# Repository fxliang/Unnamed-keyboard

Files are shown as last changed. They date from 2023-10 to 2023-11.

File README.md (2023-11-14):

The Unnamed Keyboard is a 42-key, diodeless, flippable, low profile choc v1 or MX 3 pin switch hotswap, IO protected, aggressive column staggered, programmable ergonomic mechnical split keyboard powered by Rasyberry Pi Pico or other compatible RP2040 boards. It is based on the [Piantor](https://github.com/beekeeb/piantor) Keyboard. 
## Features

* Powered by RP2040 MCU with Raspberry Pi Pico
* Cantor & Corne like layout
* Flippable layout
* Diodeless
* Split hand pin for automatically left hand detection, single firmware for both sides
* TRRS with resistor protection, hot-plug no damage 
* Hybrid hotswap: low profile choc switches and MX switches(3pin)

## BOM
* Raspberry Pi Pico (or compatible one) * 2
* choc swtiches / MX(3pin) switches * 42
* hotswap sockets for choc swtiches / MX(3pin) switches * 42
* TRRS sockets * 2, C128990(JLC),or PJ-393-7P in tb.
* 3.5mm TRRS wire (4 pin)
* 100r 0805 resistor * 4 (for io protection)
* 1k 0805 resistor *  2 (for hand pin detection)

## Images
top left
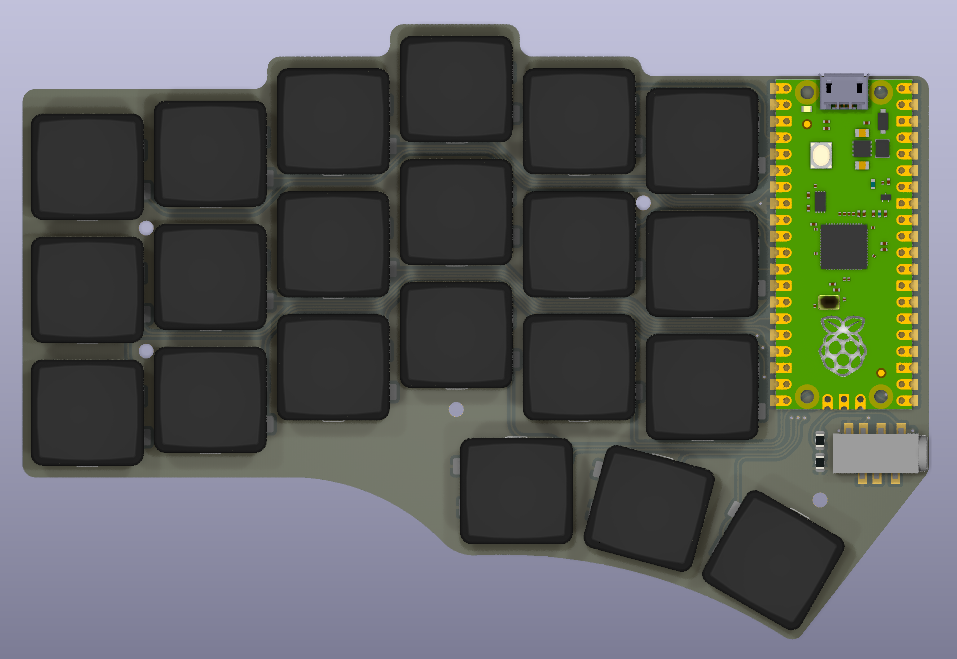
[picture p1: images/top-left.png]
left-top


bottom left(ignore the TRRS connector and pico:)
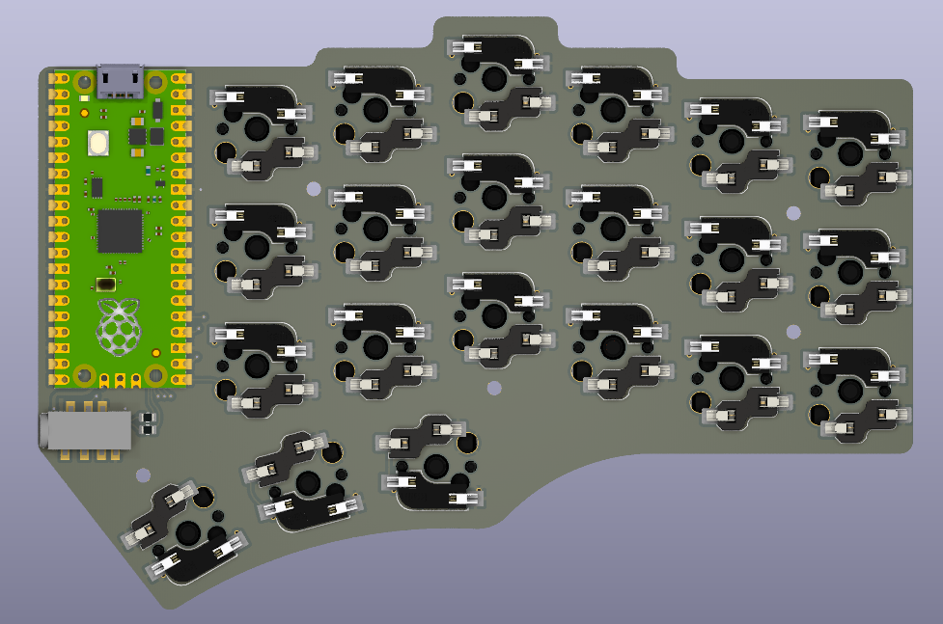
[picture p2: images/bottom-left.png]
bottom-top


pcb top
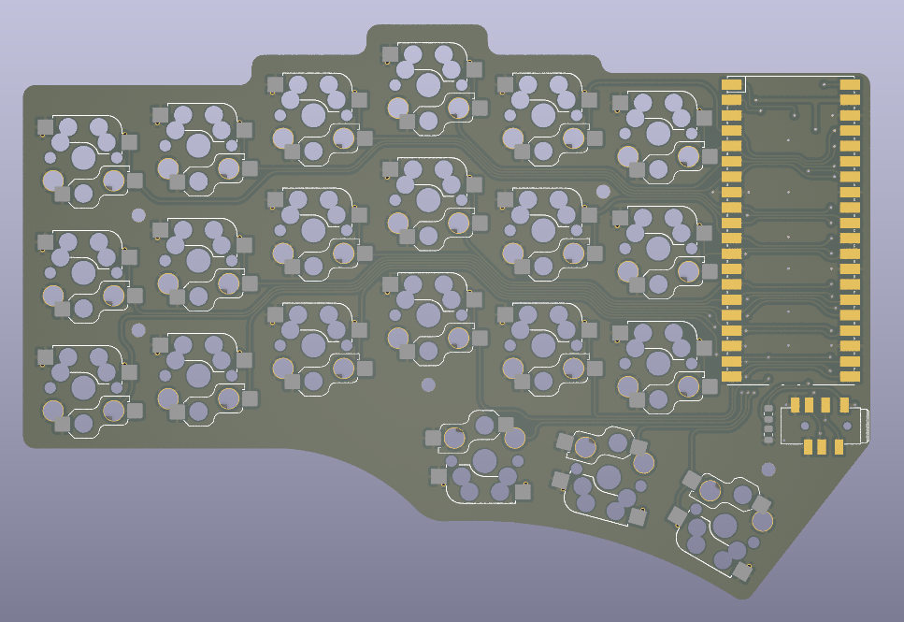
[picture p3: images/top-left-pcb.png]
pcb top


pcb bottom
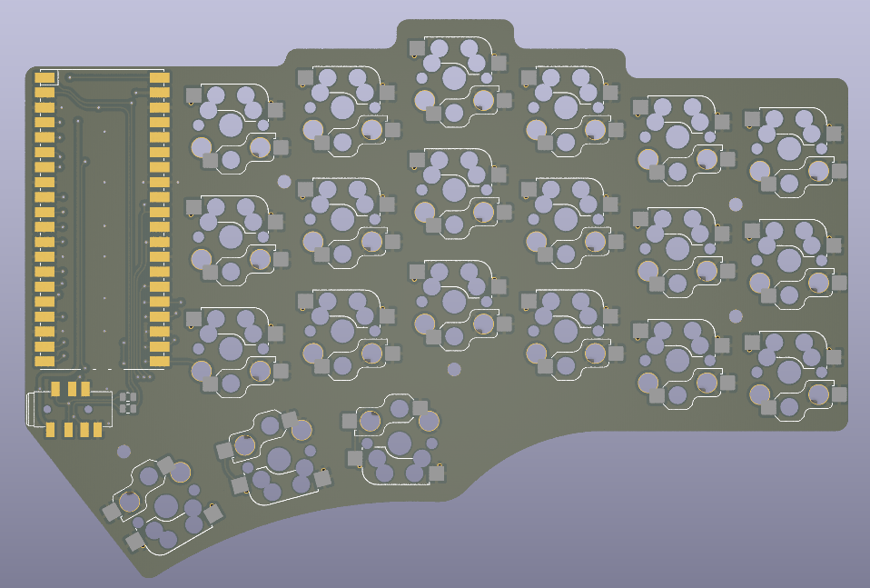
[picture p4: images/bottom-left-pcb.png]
pcb bottom


first made 


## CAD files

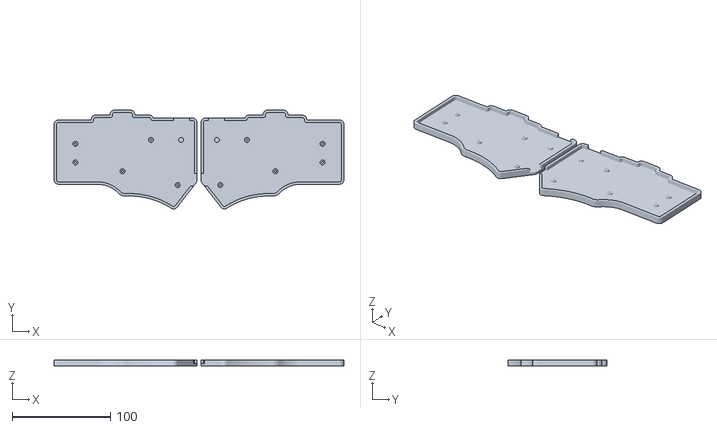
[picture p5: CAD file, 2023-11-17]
case.stl
294.8 x 100.4 x 6.30

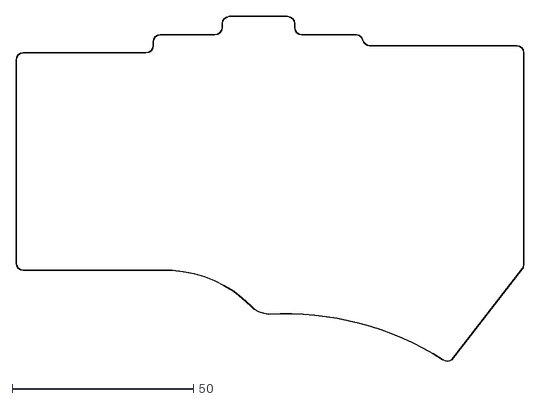
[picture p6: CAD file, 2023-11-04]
dxfs/unnamed-Edge_Cuts.dxf
140.0 x 95.1

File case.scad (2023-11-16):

$fn = 256;
pcb_edge_file = "dxfs/unnamed-Edge_Cuts.dxf";
// board parameters, unit: mm
socket_1350_thickness = 1.8;
solder_thickness = 0.2;
board_thickness = 1.6;
shell_thickness = 2.5;
asm_gap = 0.2;
// case cut info, top left 0, 0
type_c_cut_x = 133.5;
type_c_cut_y = -61.5;
type_c_cut_width = 15.8;
type_c_cut_height = 13;
trrs_cut_x = 119;
trrs_cut_y = 0;
trrs_cut_width = 16;
trrs_cut_height = 10;
// board info
board_width = 140;
board_height = 95.0130;
// gap between two cases
case_gap_l2r = 4;
// ----------------------------------------------------------------------------

total_case_height = shell_thickness + socket_1350_thickness + solder_thickness 
+ board_thickness + asm_gap;
shell_diff_height = total_case_height;
case_width = (asm_gap+shell_thickness)*2 + board_width;
offset_base_pcb = shell_thickness + asm_gap;
// ----------------------------------------------------------------------------
// case outline with offset 
module offset_shape() {
  offset(r=offset_base_pcb) import(pcb_edge_file);
}

// extrude base body, from z = 0
module base(){
  linear_extrude(height=total_case_height, center=false) {
    offset_shape();
  }
}

// add asm gap for assembly
module shape_of_shell_diff() {
    offset(r=asm_gap) import(pcb_edge_file);
}

// extrude shape for diff shell
module shell_diff() {
  translate([0, 0, shell_thickness ])
  linear_extrude(height = shell_diff_height, center = false) {
    shape_of_shell_diff();
  }
}
// type_c connector cut
module type_c_diff() {
  translate([type_c_cut_x, type_c_cut_y - type_c_cut_height, shell_thickness])
  cube([type_c_cut_width, type_c_cut_height, total_case_height]);
}

// trrs connector cut
module trrs_diff() {
  translate([trrs_cut_x, trrs_cut_y, shell_thickness])
  // mirror y axis
  mirror([0, -1, 0])
  cube([trrs_cut_width, trrs_cut_height, total_case_height]);
}

// shell case difference by  base() and shell_diff()
module shell_shape() {
  difference(){
    base();
    // cut type_c_diff
    type_c_diff();
    // cut trrs_diff
    trrs_diff();
    // cut shell
    shell_diff();
  }
}

module mount_poles() {
  translate([19.1, -31.6, shell_thickness]) {
    cylinder(h = socket_1350_thickness + solder_thickness, r = shell_thickness);
  }
  translate([19.1, -50.5, shell_thickness]) {
    cylinder(h = socket_1350_thickness + solder_thickness, r = shell_thickness);
  }
  translate([67.0, -59.5, shell_thickness]) {
    cylinder(h = socket_1350_thickness + solder_thickness, r = shell_thickness);
  }
  translate([95.9, -27.6, shell_thickness]) {
    cylinder(h = socket_1350_thickness + solder_thickness, r = shell_thickness);
  }
  translate([126.5, -27.6, shell_thickness]) {
    cylinder(h = socket_1350_thickness + solder_thickness, r = shell_thickness);
  }
  translate([123, -73.5, shell_thickness]) {
    cylinder(h = socket_1350_thickness + solder_thickness, r = shell_thickness);
  }
}
module mount_holes() {
  translate([19.1, -31.6, -shell_thickness]) {
    cylinder(h = total_case_height*2, r = 1);
  }
  translate([19.1, -50.5, -shell_thickness]) {
    cylinder(h = total_case_height*2, r = 1);
  }
  translate([67.0, -59.5, -shell_thickness]) {
    cylinder(h = total_case_height*2, r = 1);
  }
  translate([95.9, -27.6, -shell_thickness]) {
    cylinder(h = total_case_height*2, r = 1);
  }
  translate([123, -73.5, -shell_thickness]) {
    cylinder(h = total_case_height*2, r = 1);
  }
}
// left case
module left_case() {
  // move the left of case to x = 0
  difference() {
    translate([(shell_thickness + asm_gap), 0, 0]){
        mount_poles();
        shell_shape();
    }
    translate([(shell_thickness + asm_gap), 0, 0]){
        mount_holes();
    }
  }
}

// right case
module right_case() {
  // move to the right, add case_gap_l2r
  translate([case_width*2 + case_gap_l2r, 0, 0])
  // mirror x axis
  mirror([-1,0,0])
  // left case
  left_case();
}
// use modules
left_case();
right_case();

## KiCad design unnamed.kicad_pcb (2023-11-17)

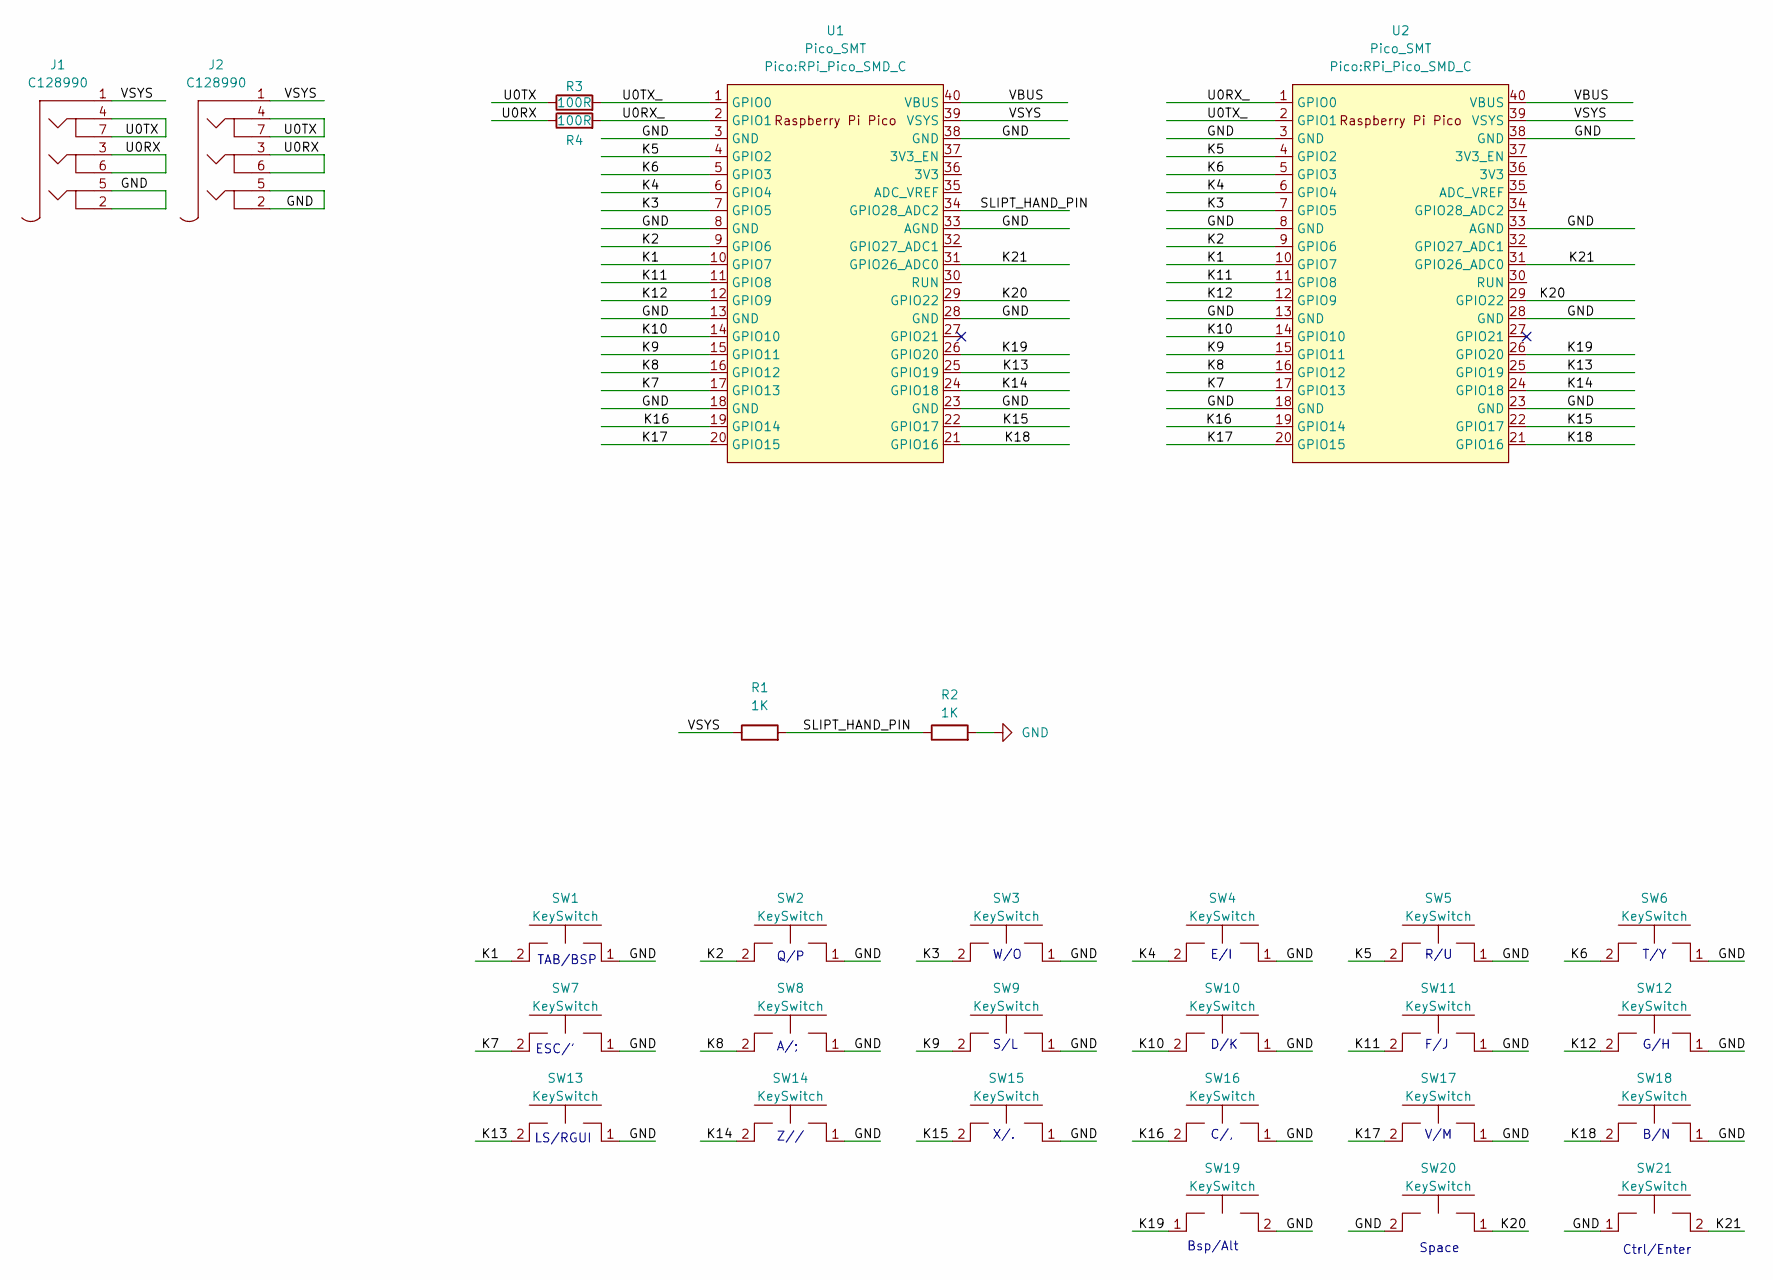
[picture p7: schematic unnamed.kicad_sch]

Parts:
J1, J2: C128990; C128990_3.5MM_TRRS
R1, R2: 1K; R_0805_2012Metric_Pad1.20x1.40mm_HandSolder
R3, R4: 100R; R_0805_2012Metric_Pad1.20x1.40mm_HandSolder
SW1, SW2, SW3, SW4, SW5, SW6, SW7, SW8, SW9, SW10, SW11, SW12, SW13, SW14, SW15, SW16, SW17, SW18, SW19, SW20, SW21: KeySwitch; SW_Hotswap_Kailh_Choc_V1_MX_COMBO
U1, U2: Pico_SMT; RPi_Pico_SMD_C

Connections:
/K1: SW1.2, U1.10 (GPIO7), U2.10 (GPIO7)
/K2: SW2.2, U1.9 (GPIO6), U2.9 (GPIO6)
/K3: SW3.2, U1.7 (GPIO5), U2.7 (GPIO5)
/K4: SW4.2, U1.6 (GPIO4), U2.6 (GPIO4)
/K5: SW5.2, U1.4 (GPIO2), U2.4 (GPIO2)
/K6: SW6.2, U1.5 (GPIO3), U2.5 (GPIO3)
/K7: SW7.2, U1.17 (GPIO13), U2.17 (GPIO13)
/K8: SW8.2, U1.16 (GPIO12), U2.16 (GPIO12)
/K9: SW9.2, U1.15 (GPIO11), U2.15 (GPIO11)
/K10: SW10.2, U1.14 (GPIO10), U2.14 (GPIO10)
/K11: SW11.2, U1.11 (GPIO8), U2.11 (GPIO8)
/K12: SW12.2, U1.12 (GPIO9), U2.12 (GPIO9)
/K13: SW13.2, U1.25 (GPIO19), U2.25 (GPIO19)
/K14: SW14.2, U1.24 (GPIO18), U2.24 (GPIO18)
/K15: SW15.2, U1.22 (GPIO17), U2.22 (GPIO17)
/K16: SW16.2, U1.19 (GPIO14), U2.19 (GPIO14)
/K17: SW17.2, U1.20 (GPIO15), U2.20 (GPIO15)
/K18: SW18.2, U1.21 (GPIO16), U2.21 (GPIO16)
/K19: SW19.1, U1.26 (GPIO20), U2.26 (GPIO20)
/K20: SW20.1, U1.29 (GPIO22), U2.29 (GPIO22)
/K21: SW21.2, U1.31 (GPIO26_ADC0), U2.31 (GPIO26_ADC0)
/SLIPT_HAND_PIN: R1.2, R2.1, U1.34 (GPIO28_ADC2)
/U0RX: J1.3, J1.6, J2.3, J2.6, R4.1
/U0RX_: R4.2, U1.2 (GPIO1), U2.1 (GPIO0)
/U0TX: J1.4, J1.7, J2.4, J2.7, R3.1
/U0TX_: R3.2, U1.1 (GPIO0), U2.2 (GPIO1)
/VBUS: U1.40 (VBUS), U2.40 (VBUS)
/VSYS: J1.1, J2.1, R1.1, U1.39 (VSYS), U2.39 (VSYS)
GND: J1.2, J1.5, J2.2, J2.5, R2.2, SW1.1, SW2.1, SW3.1, SW4.1, SW5.1, SW6.1, SW7.1, SW8.1, SW9.1, SW10.1, SW11.1, SW12.1, SW13.1, SW14.1, SW15.1, SW16.1, SW17.1, SW18.1, SW19.2, SW20.2, SW21.1, U1.3 (GND), U1.8 (GND), U1.13 (GND), U1.18 (GND), U1.23 (GND), U1.28 (GND), U1.33 (AGND), U1.38 (GND), U2.3 (GND), U2.8 (GND), U2.13 (GND), U2.18 (GND), U2.23 (GND), U2.28 (GND), U2.33 (AGND), U2.38 (GND)

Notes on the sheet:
G/H
E/I
Bsp/Alt
D/K
Z//
C/,
W/O
F/J
ESC/'
Space
R/U
Q/P
Ctrl/Enter
V/M
S/L
X/.
B/N
LS/RGUI
T/Y
A/;
TAB/BSP

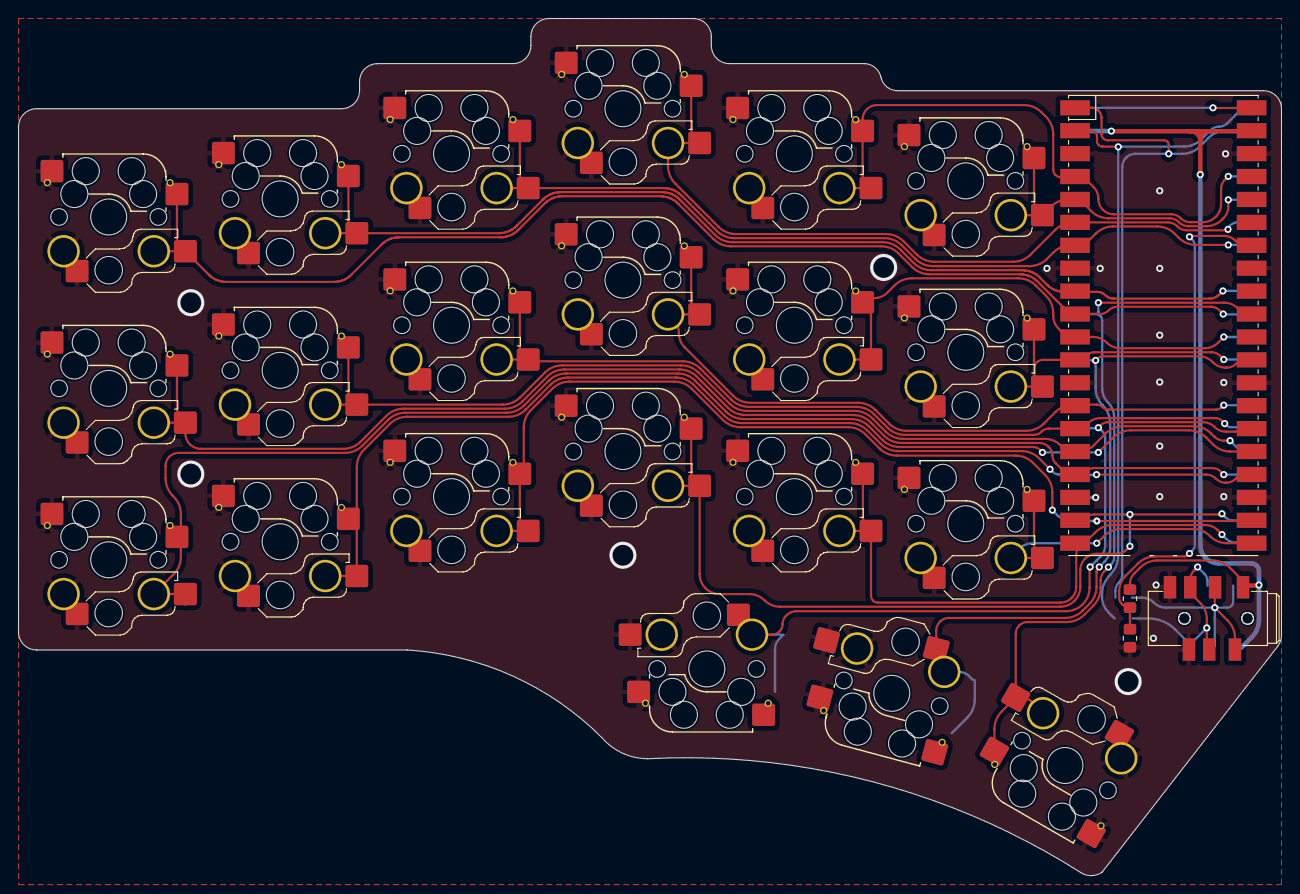
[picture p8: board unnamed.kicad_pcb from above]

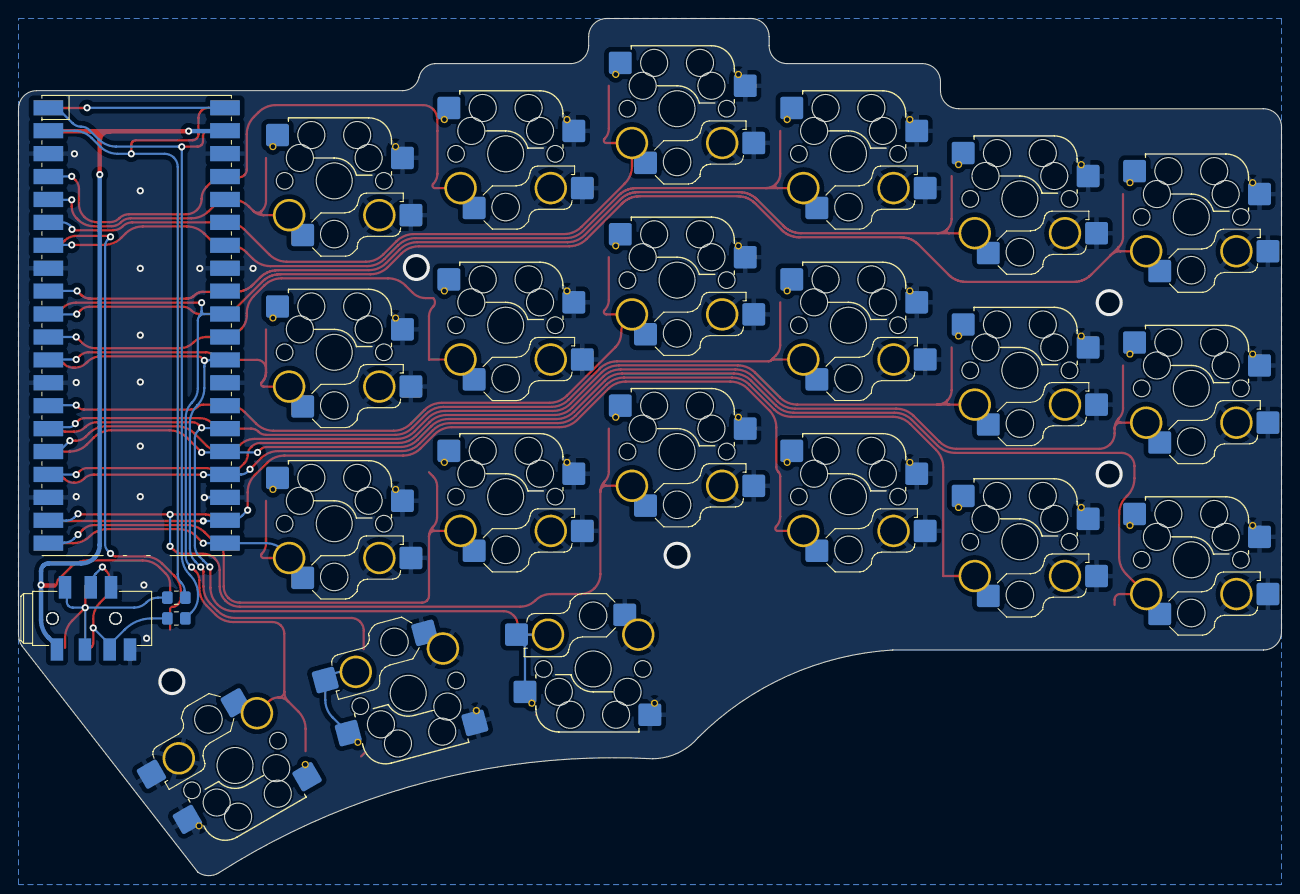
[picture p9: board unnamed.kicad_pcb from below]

Board: 2 copper layers, 140.0 x 95.0 mm, 29 parts (4 on the bottom side), 29 nets.

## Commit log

2023-10-30 first files commit
    [unnamed.kicad_pcb, unnamed.kicad_sch]
2023-10-31 update pcb with edge modification a little bit. add case
    [left.STEP, right.STEP, unnamed.kicad_pcb]
2023-11-01 fix drc issue
    [unnamed.kicad_pcb]
2023-11-02 update pcb and project, new 3d file for cases.
    [case.scad, left.STEP, right.STEP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]
2023-11-04 add parameter info in pcb in user layer modify case model with parameters add Edge_Cuts dxf file add case.stl
    [case.scad, case.stl, unnamed-Edge_Cuts.dxf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]
2023-11-10 update footprint
    [unnamed.kicad_pcb]
2023-11-15 update switch footprint, change 0805 to hand-solder footprint, update schematic value.
    [unnamed.kicad_pcb, unnamed.kicad_sch]
2023-11-16 update key footprint, update case design(not tested yet)
    [case.scad, unnamed.kicad_pcb]
2023-11-17 update pcb title, update stl file
    [case.stl, unnamed.kicad_pcb]
